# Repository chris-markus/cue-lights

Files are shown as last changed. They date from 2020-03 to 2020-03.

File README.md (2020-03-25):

# DIY Cue Light System

This Repo contains all of the neccesary hardware and software to implement a 10 station cue light system for use in a theater or other semi-permanent installation. As of March 2020, you can put this system together for well under $500.00 which is exceptional value when compared with competing commercial products. This project was originally developed for the Tufts University Theater department and is currently installed in the Balch Arena Theater.

For videos and photos of the finished system (and proof that it works...) visit the [project page](https://chrismarkus.me/cue-lights) on my website.

DISCLAIMER: *This project is intended for ADVANCED users only! That is, you need advanced soldering skills and an in-depth understanding of circuits and electrical systems is recommended to put it together. I am not responsible for any damages should you choose to put this system together yourself - use at your own risk...*

## Contents

**/controller:** Contains Arduino code that runs on the Arduino Mega that acts as the controller for the system.  
**/reciever:** Contains Arduino code that runs on the arduino nano inside of each cue light box.  
**/hardware_controller:** Contains schematics and guides for building the controller box.  
**/hardware_receiver:** Contains schematics, guides, and PCB (Printed Circuit Board) manufacturing files to order the circuit boards within each cue light box.

## Getting Started

If you would like to replicate this project, I recommend you do a few things first:

1. Read the entirety of these instructions (there are a few subtleties that could make or break the project for you)!
2. Make sure you can source all of the parts needed to build the final product or suitable replacements (See a parts list [here](https://github.com/chris-markus/cue-lights/blob/master/parts_list.md)).
3. Make sure you have the neccesary tools:
    - Soldering Iron, Solder, Flux, tweezers (there is 1 surface mount component)
    - Access to a laser cutter **or** a drill, files, and lots of patience.
    - A rotary tool or other plastic-cutting solution if you are using the same boxes for the clue light stations as I was (you will have to make some square holes in the boxes for the ethernet jacks - more on that later).

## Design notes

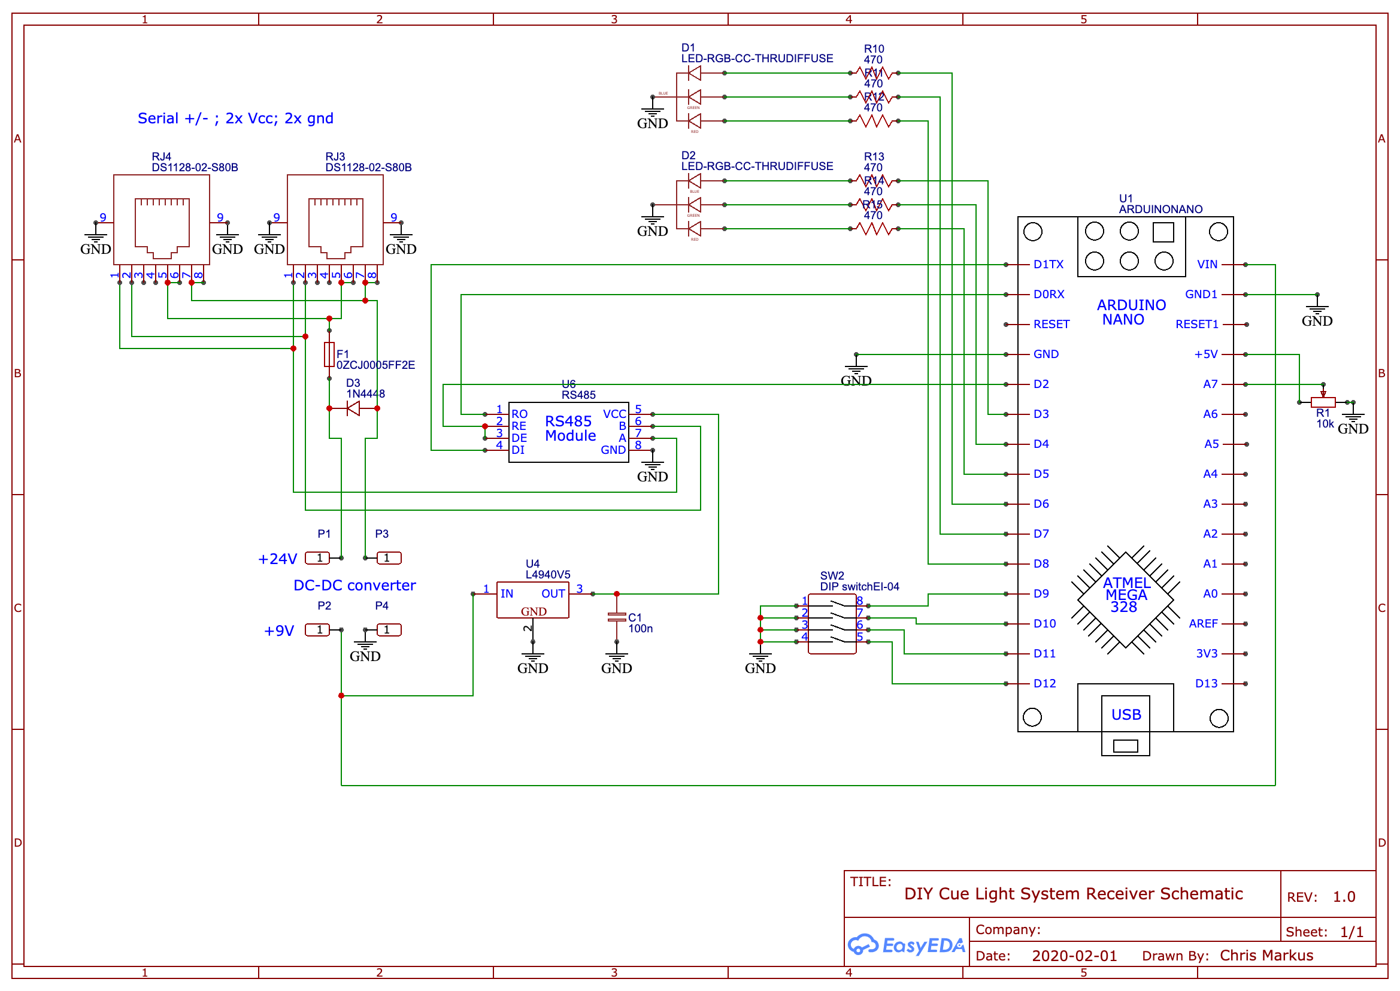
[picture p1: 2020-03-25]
hardware_reciever/reciever_schematic.png

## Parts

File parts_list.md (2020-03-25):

# Parts List

*All of these part links are what I used but the parts are certainly available elsewhere or from other sellers on Amazon. This list was compiled in March 2020 and availability may change.*

| Qty. | Description | Link | Total Price |
| - | - | - | - |
| 1 | Arduino Mega | [Amazon](https://www.amazon.com/dp/B01H4ZDYCE/?coliid=I38YO9YL3XBXYL&colid=2FJIVCIG61FZ3&psc=1&ref_=lv_ov_lig_dp_it)
| 1 | Pack of headers | [Amazon](https://www.amazon.com/dp/B074HVBTZ4/?coliid=I2SALIENF1E35N&colid=2FJIVCIG61FZ3&psc=1&ref_=lv_ov_lig_dp_it)
| 1 | Pack of hookup wires | [Amazon](https://www.amazon.com/dp/B01EV70C78/?coliid=I25YAA6RHEZLDY&colid=2FJIVCIG61FZ3&psc=1&ref_=lv_ov_lig_dp_it)
| 10 | Arduino Nano | [Amazon](https://www.amazon.com/Longruner-ATmega328P-Controller-Module-Arduino/dp/B01MSYWE6B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)
| 11+ | Max485 Module | [Amazon](https://www.amazon.com/Max485-Chip-RS-485-Module-Raspberry/dp/B00NIOLNAG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)
| 11+ | Buck Converter | [Amazon](https://www.amazon.com/dp/B01GJ0SC2C/?coliid=I3JBHTT7ABGMOY&colid=2FJIVCIG61FZ3&psc=1&ref_=lv_ov_lig_dp_it)
| 1 | 24V Power Adapter<sup>1</sup> (>30W) | [Amazon](https://www.amazon.com/gp/product/B01MUHM9RS/ref=ppx_yo_dt_b_asin_title_o06_s00?ie=UTF8&th=1)
| 1 | Female DC Barrel Jack | [Amazon](https://www.amazon.com/gp/product/B07MPS3QD8/ref=ppx_yo_dt_b_asin_title_o04_s00?ie=UTF8&psc=1)
| 10 | Project boxes (at least 9.6 x 5.6 x 2.3 cm inner dimension) | [Amazon](https://www.amazon.com/dp/B07G8S6XLV/?coliid=I3E26J4OOMT4EH&colid=2FJIVCIG61FZ3&psc=1&ref_=lv_ov_lig_dp_it)
| 10 | 4-bank of dip-switches | [Amazon](https://www.amazon.com/dp/B07V3579RT/?coliid=IUU33GC5I2TAI&colid=2FJIVCIG61FZ3&psc=1&ref_=lv_ov_lig_dp_it)
| 1 | OLED Display (Adafruit SSD1306 compatible) | [Amazon](https://www.amazon.com/dp/B076WXR8N9/?coliid=I19JJOJC0VQFZV&colid=2FJIVCIG61FZ3&psc=1&ref_=lv_ov_lig_dp_it)
| 1 | Project Enclosure (this one was really great quality) | [Amazon](https://www.amazon.com/dp/B005T58ZTO/?coliid=I29AJ8ZW90XZUX&colid=2FJIVCIG61FZ3&psc=1&ref_=lv_ov_lig_dp_it)
| 32+ | 10mm RGB LED (Common Cathode) | [Amazon](https://www.amazon.com/dp/B01CI6EWHK/?coliid=I1IVWGD1GD914&colid=2FJIVCIG61FZ3&psc=1&ref_=lv_ov_lig_dp_it)
| | Component order (From DigiKey)<sup>2</sup> | [Saved Cart](https://www.digikey.com/short/zjcjcv) | $72.72+ shipping |

<sup>1</sup> Be sure to get one that is UL-Listed  
<sup>2</sup> The quantities in the cart are (as best I can recall) EXACT. It is a fantastic idea to order extra of everything (and in some cases will actually be less expensive due to volume pricing).

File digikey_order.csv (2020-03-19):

Index | Quantity | Part Number | Manufacturer Part Number | Description | Customer Reference | Available | Backorder | Unit Price | Extended Price USD
1 | 1 | RXEF110-ND | RXEF110 | PTC RESET FUSE 72V 1.1A RADIAL |  | 1 | 0 | 0.46000 | 0.46
2 | 1 | 401-1288-ND | DA102J12S215PQF | SWITCH ROCKER SPST 16A 125V |  | 0 | 1 | 1.32000 | 1.32
3 | 1 | CF14JT120RCT-ND | CF14JT120R | RES 120 OHM 1/4W 5% AXIAL |  | 1 | 0 | 0.10000 | 0.10
4 | 1 | 1568-1601-ND | COM-10002 | KNOB KNURLED 0.236" METAL |  | 1 | 0 | 1.50000 | 1.50
5 | 32 | 1N4148FSCT-ND | 1N4148TR | DIODE GEN PURP 100V 200MA DO35 |  | 32 | 0 | 0.05360 | 1.72
6 | 10 | 507-1793-1-ND | 0ZCJ0005FF2E | PTC RESET FUSE 60V 50MA 1206 |  | 10 | 0 | 0.12500 | 1.25
7 | 1 | PEC11R-4215F-S0024-ND | PEC11R-4215F-S0024 | ROTARY ENCODER MECHANICAL 24PPR |  | 0 | 1 | 1.68000 | 1.68
8 | 11 | 493-12812-1-ND | UVR2A0R1MDD1TD | CAP ALUM 0.1UF 20% 100V RADIAL |  | 11 | 0 | 0.16400 | 1.80
9 | 11 | 497-1404-5-ND | L4940V5 | IC REG LINEAR 5V 1.5A TO220AB |  | 11 | 0 | 1.35100 | 14.86
10 | 22 | CF14JT10K0CT-ND | CF14JT10K0 | RES 10K OHM 1/4W 5% AXIAL |  | 22 | 0 | 0.04000 | 0.88
11 | 66 | CF14JT470RCT-ND | CF14JT470R | RES 470 OHM 1/4W 5% AXIAL |  | 66 | 0 | 0.02200 | 1.45
12 | 11 | BC33740TACT-ND | BC33740TA | TRANS NPN 45V 0.8A TO-92 |  | 11 | 0 | 0.24600 | 2.71
13 | 22 | AE10387-ND | A-2004-2-4-LPS-N-R | CONN MOD JACK 8P8C R/A SHIELDED |  | 22 | 0 | 0.92300 | 20.31
14 | 11 | 401-1976-ND | D6R50 F1 LFS | SWITCH PUSH SPST-NO 0.1A 32V |  | 11 | 0 | 1.17000 | 12.87
15 | 11 | 401-1975-ND | D6R40 F1 LFS | SWITCH PUSH SPST-NO 0.1A 32V |  | 11 | 0 | 0.89200 | 9.81

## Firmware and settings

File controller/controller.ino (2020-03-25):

// =====================================================
// Copyright (C) 2020 Christopher Markus 
// www.chrismarkus.me
// This software is licensed under the GNU GPLv3 License
// =====================================================

// Required libraries:
// Encoder: Arduino Package Manager
// Wire.h: Arduino Package Manager
// Adafruit_SSD1306: Arduino Package Manager
// EEPROM: included with Arduino
// Adafruit_GFX: Arduino Package Manager
// digitalWriteFast: install from here: https://github.com/NicksonYap/digitalWriteFast
// CueLightsCommon: In git repo (follow instructions in README)

// include libraries
#define ENCODER_OPTIMIZE_INTERRUPTS
#include <Encoder.h>
#include <Wire.h>
#include <EEPROM.h>
#include <digitalWriteFast.h>

// include our source files
#include <CueLightsCommon.h>
#include "strings.h"
#include "lcd_screen.h"
#include "ui_controller.h"
#include "menu.h"
#include "settings.h"
#include "constants.h"
#include "station.h"

// uncomment the following line to allow debug printing
// #define DEBUG

// some global objects
CLCDebouncedButton encoderButton(encoderButtonPin, ACTIVE_LOW_PULLUP);
LCDScreen screen(SCREEN_WIDTH, SCREEN_HEIGHT, &Wire);
Encoder encoder(encoderPins[0], encoderPins[1]);
// references to our UI controllers
NavigationController* navigation;
UIController* interface;
// panel buttons
CLCDebouncedButton stationButtons[(MAX_STATIONS + 1)][2] = {47,47,45,45,43,43,41,41,39,39,37,37,35,35,33,33,31,31,29,29,27,27};

// global status
enum GlobalStatusEnum {
  BUSY,
  OK,
  FAULT,
} GlobalStatus = BUSY;

// states for cue light communication state machine
enum ControllerState {
  STATION_REQUEST,
  STATION_RESPONSE,
  SEND_COLOR,
  BREAK,
  WAIT,
};

// Interrupt Service Routine to update panel LEDs every 0.5ms and ensure no flickering
// If you use pixel-mapped leds, this will no longer be neccessary!
ISR(TIMER4_OVF_vect) {
  TCNT4 = TIMER_COUNTER_PRELOAD;
  static int i = 0;
  analogWrite(ledPwmPins[0], 0);
  analogWrite(ledPwmPins[1], 0);
  analogWrite(ledPwmPins[2], 0);
  // use a macro to write using digitalWriteFast
  digitalWriteLEDEnable(i, LOW);
  i = (i + 1) % (MAX_STATIONS + 1);
  digitalWriteLEDEnable(i, HIGH);
  analogWrite(ledPwmPins[0], panelIndicators[i].r);
  analogWrite(ledPwmPins[1], panelIndicators[i].g);
  analogWrite(ledPwmPins[2], panelIndicators[i].b);
}

unsigned long birthTime;

void setup() {
  // pin setup that isn't taken care of by classes/other functions:
  pinMode(transmitPin, OUTPUT);
  digitalWrite(transmitPin,LOW);
  for (int i=0; i<3; i++) {
    pinMode(statusLEDPins[i], OUTPUT);
  }
  updateGlobalStatusLED();

  pinMode(buttonStbyEnable, OUTPUT);
  pinMode(buttonGoEnable, OUTPUT);

  #ifdef DEBUG
  Serial.begin(CLC_DEFAULT_BAUD_RATE);
  #endif

  // initialize settings and stations (cue light boxes):
  InitSettings();
  InitStations();

  // begin serial connection(s)
  STATION_SERIAL.begin(CLC_DEFAULT_BAUD_RATE);

  // setup ISR and change pwm frequency
  noInterrupts();
  // setup ISR on timer 4 to run face panel light code
  TCCR4A = 0;
  TCCR4B = 0;
  TIMSK4 |= (1 << TOIE1); // enable timer overflow interrupt
  TCCR4B |= (1 << CS12); // 256 prescaler
  TCNT4 = TIMER_COUNTER_PRELOAD; // preload timer 65536-16MHz/256/2Hz

  // increase PWM frequency of timers 1 and 2 to help reduce panel light flickering
  TCCR2B = TCCR2B & 0b11111000 | 0x01;
  TCCR1B = TCCR1B & 0b11111000 | 0x01;
  interrupts();

  // screen setup
  screen.init();
  screen.showSplash();

  // Screens created in menu-definitions.ino
  navigation = new NavigationController(&screen, &homeScreen);
  interface = new UIController(&encoder, &encoderButton, navigation);

  birthTime = millis();
}

bool initialSet = false;

void loop() {
  if (!initialSet && millis() > birthTime + 1000) {
    GlobalStatus = OK;
    initialSet = true;
  }
  detectButtonPresses();
  updateFacePanelLights();
  interface->tick();
  updateGlobalStatusLED();
  HandleCommunication();
}

void resetSettings() {
  resetDefaultSettings();
  navigation->goHome();
}

void getConnStatusString(char* input) {
  uint8_t count = 0;
  for(int i=0; i<MAX_STATIONS; i++) {
    count += stations[i].connStatus == CONNECTED;
  }
  sprintf(input, STR_LIGHTS_STATUS, count);
}

int getNextDisconnectedStation(int& numDisconnected) {
  static unsigned long lastUpdate = 0;
  const uint16_t updateInterval = 1500;
  static int currentStation = 0;
  bool connected[MAX_STATIONS];
  bool fault = false;
  numDisconnected = 0;
  for (int i=0; i<MAX_STATIONS; i++) {
    if (stations[currentStation].connStatus != CONNECTED 
        && stations[i].lastSeen != 0
        && millis() - stations[i].lastSeen > STATION_DISCONNECT_TIMEOUT 
        && millis() - stations[i].lastSeen < 100000)
    {
      if (millis() - stations[i].lastSeen < 10000) {
        fault = true;
      }
      connected[i] = false;
      numDisconnected++;
    }
    else {
      connected[i] = true;
    }
  }
  if (stations[currentStation].connStatus == CONNECTED || millis() > lastUpdate + updateInterval) {
    lastUpdate = millis();
    for (int i=currentStation+1; i<MAX_STATIONS + currentStation + 1; i++) {
      if (!connected[i%MAX_STATIONS]) {
        currentStation = i%MAX_STATIONS;
        break;
      }
    }
  }
  if (fault) {
    GlobalStatus = FAULT;
  }
  else {
    GlobalStatus = OK;
  }
  if (numDisconnected > 0) {
    return currentStation;
  }
  else {
    return -1;
  }
}

void getGlobalStatusString(char* input) {
  int numIssues = 0;
  int i = getNextDisconnectedStation(numIssues);
  if (i != -1) {
    sprintf(input, STR_ISSUES, numIssues);
  }
  else {
    sprintf(input, STR_NO_ISSUES);
  }
}

void getDescriptiveGlobalStatusString(char* input) {
  int numIssues = 0;
  int i = getNextDisconnectedStation(numIssues);
  if (i != -1) {
    sprintf(input, STR_STATION_DISCONNECTED, i+1, (millis() - stations[i].lastSeen)/1000);
  }
  else {
    sprintf(input, STR_NO_ISSUES);
  }
}

void detectButtonPresses() {
  // row 0 is standby, 1 is go
  static int buttonRow = false;
  static bool canSwap[MAX_STATIONS] = {1,1,1,1,1,1,1,1,1,1};

  digitalWrite(buttonStbyEnable, buttonRow);
  digitalWrite(buttonGoEnable, !buttonRow);

  // button press detection loop
  for (int i=0; i<MAX_STATIONS; i++) {
    if (stations[i].connStatus == CONNECTED) {
      CueStatus status = stations[i].cueStatus;
      if (stationButtons[i][buttonRow].isPressed()) {
        if (canSwap[i]) {
          if (status == NONE || buttonRow != (status == STBY)) {
            // if the status is none or if the status is not the same as the 
            // button we are pressing, set the status to correspond to the button
            stations[i].cueStatus = buttonRow?STBY:GO;
          }
          else {
            // otherwise, set it to NONE
            stations[i].cueStatus = NONE;
          }
          canSwap[i] = false;
        }
      }
      else if (stationButtons[i][buttonRow].wasReleased()) {
        canSwap[i] = true;
      }
    }
  }

  // master stby or go pressed
  if (stationButtons[MAX_STATIONS][buttonRow].isPressed()) {
    for (int i=0; i<MAX_STATIONS; i++) {
      switch (stations[i].cueStatus) {
        case STBY:
            stations[i].cueStatus = buttonRow?NONE:GO;
          break;
        case GO:
          if (buttonRow) {
            stations[i].cueStatus = NONE;
          }
          break;
        case NONE:
          break;
      }
    }
  }

  buttonRow = !buttonRow;
}

void updateFacePanelLights() {
  static bool flashOn = true;
  static unsigned long lastFlashChange = 0;

  if (flashOn && millis() > FLASH_DELAY_ON + lastFlashChange || 
      !flashOn && millis() > FLASH_DELAY_OFF + lastFlashChange)
  {
    flashOn = !flashOn;
    lastFlashChange = millis();
  }

  int stby = -1;
  int go = -1;
  int connected = -1;

  // color update loop
  for(int i=0; i< MAX_STATIONS; i++) {
    if (stations[i].connStatus == CONNECTED) {
      connected = i;
      if (stations[i].cueStatus == STBY) {
        stby = i;
        if (!flashOnStandby.value || flashOnStandby.value && flashOn) {
          stations[i].color = getScaledColor(RGBColor {standbyColor[0].value, standbyColor[1].value, standbyColor[2].value},
                                             stationBrightness[i].max,
                                             stationBrightness[i].value);
        }
        else {
          stations[i].color = {0,0,0};
        }
        panelIndicators[i] = getScaledColor(stations[i].color, panelBrightness.max, panelBrightness.value);
      }
      else if (stations[i].cueStatus == GO) {
        go = i;
        stations[i].color = getScaledColor(RGBColor {goColor[0].value, goColor[1].value, goColor[2].value},
                                           stationBrightness[i].max,
                                           stationBrightness[i].value);
        panelIndicators[i] = getScaledColor(stations[i].color, panelBrightness.max, panelBrightness.value);
      }
      else {
        stations[i].color = {0,0,0};
        panelIndicators[i] = {0,0,12};
      }
    }
    else {
      panelIndicators[i] = {0,0,0};
    }
  }

  if (stby != -1) {
    if (!flashOnStandby.value || flashOnStandby.value && flashOn) {
      panelIndicators[MAX_STATIONS] = getScaledColor(RGBColor {standbyColor[0].value, standbyColor[1].value, standbyColor[2].value},
                                                     panelBrightness.max,
                                                     panelBrightness.value);
    }
    else {
      panelIndicators[MAX_STATIONS] = {0,0,0};
    }
  }
  else if (go != -1) {
    panelIndicators[MAX_STATIONS] = getScaledColor(RGBColor {goColor[0].value, goColor[1].value, goColor[2].value},
                                                   panelBrightness.max,
                                                   panelBrightness.value);
  }
  else if (connected != -1) {
    panelIndicators[MAX_STATIONS] = panelIndicators[connected];
  }
  else {
    panelIndicators[MAX_STATIONS] = {0,0,0};
  }
}

RGBColor getScaledColor(RGBColor c, uint8_t max, uint8_t value) {
  c.r = (uint8_t)((uint16_t)(c.r)*(uint16_t)(value)/(uint16_t)(max));
  c.g = (uint8_t)((uint16_t)(c.g)*(uint16_t)(value)/(uint16_t)(max));
  c.b = (uint8_t)((uint16_t)(c.b)*(uint16_t)(value)/(uint16_t)(max));
  return c;
}

// Handles all communication with the cue light stations. See "CueLightsCommon.h" for 
// in-depth protocol descriptions.
void HandleCommunication() {
  static ControllerState controllerState = BREAK;
  static uint8_t responseStation = 0;
  int len = 0;
  char sendBuff[CLC_DATA_LEN + CLC_OVERHEAD]; // start + type + data + 2 end chars
  static char recvBuffer[CLC_STATUS_LEN + CLC_OVERHEAD + 1]; // start + type + synced + end
  static int recvIndex = 0;
  static unsigned long requestSent = 0;
  static unsigned long waitStart = 0;
  bool doneReceiving = false;
  char ch;

  switch(controllerState) {
    case SEND_COLOR:
      sendBuff[len++] = CLC_PKT_START;
      sendBuff[len++] = PKT_TYPE_CONTROL;
      for (int i=0; i<MAX_STATIONS; i++) {
        sendBuff[len++] = stations[i].color.r;
        sendBuff[len++] = stations[i].color.g;
        sendBuff[len++] = stations[i].color.b;
      }
      sendBuff[len++] = CLC_PKT_END;

      STATION_SERIAL.write(sendBuff, len);
      controllerState = STATION_REQUEST;
      break;
    case STATION_REQUEST:
      sendBuff[len++] = CLC_PKT_START;
      sendBuff[len++] = PKT_TYPE_STATUS;
      sendBuff[len++] = (char)(stations[responseStation].address);
      sendBuff[len++] = CLC_PKT_END;

      STATION_SERIAL.write(sendBuff, len);
      requestSent = millis();

      // need to make sure everything has been sent before we switch
      // no need to do this asynchronously since the delay is so short
      STATION_SERIAL.flush();
      delay(1);
      // ready to recieve
      digitalWriteFast(transmitPin, LOW);
      delay(1);

      controllerState = STATION_RESPONSE;
      break;
    case STATION_RESPONSE:
      if(STATION_SERIAL.available()) {
        ch = STATION_SERIAL.read();
        if (ch == CLC_PKT_START) {
          recvIndex = 0;
          recvBuffer[recvIndex++] = ch;
        }
        else if (recvIndex < CLC_STATUS_LEN + CLC_OVERHEAD) {
          recvBuffer[recvIndex++] = ch;
        }
      }

      // recieved packet: |START|TYPE|ADDRESS (as char)|SYNCHRONIZED (as char)|END|
      //         example: | '<' |'R' |      0x03       |         0x01         |'>'|
      // we care about the synchronized byte because the cue light will not accept color commands if it is not synchronized
      if (recvIndex == CLC_STATUS_LEN + CLC_OVERHEAD &&
          recvBuffer[0] == CLC_PKT_START &&
          recvBuffer[1] == PKT_TYPE_RESPONSE &&
          recvBuffer[2] == stations[responseStation].address &&
          recvBuffer[3] == 1) {
        stations[responseStation].connStatus = CONNECTED;
        stations[responseStation].lastSeen = millis();
        doneReceiving = true;
      }
      else if (millis() > requestSent + CLC_RESPONSE_TIMEOUT) {
        #ifdef DEBUG
          Serial.print("Timeout ");
          Serial.println(stations[responseStation].address);
        #endif
        if (stations[responseStation].lastSeen < millis() - STATION_DISCONNECT_TIMEOUT) {
          stations[responseStation].connStatus = DISCONNECTED;
        }
        doneReceiving = true;

        // clear the recieve buffer
        while(STATION_SERIAL.available()) {
          STATION_SERIAL.read();
        }
      }

      if (doneReceiving) {
        digitalWriteFast(transmitPin, HIGH);
        responseStation = (responseStation + 1) % MAX_STATIONS;
        recvIndex = 0;
        delay(1);
        controllerState = BREAK;
      }
      break;
    case BREAK:
      for (int i=0; i<CLC_BREAK_LEN; i++) {
        sendBuff[len++] = CLC_PKT_END;
      }
      STATION_SERIAL.write(sendBuff, len);
      waitStart = millis();
      controllerState = WAIT;
      break;
    case WAIT:
      if (millis() > waitStart + CLC_RESPONSE_DELAY) {
        controllerState = SEND_COLOR;
      }
      break;
  }
}

void updateGlobalStatusLED() {
  const int brightness = 3;
  switch(GlobalStatus) {
    case BUSY:
      digitalWrite(statusLEDPins[1], 0);
      digitalWrite(statusLEDPins[0], 0);
      flashLED(statusLEDPins[2], 50, brightness);
      break;
    case OK:
      analogWrite(statusLEDPins[0], brightness*1.5);
      analogWrite(statusLEDPins[1], brightness/2.0);
      analogWrite(statusLEDPins[2], brightness/1.5);
      break;
    case FAULT:
      flashLED(statusLEDPins[0], 100, 30);
      digitalWrite(statusLEDPins[1], 0);
      digitalWrite(statusLEDPins[2], 0);
      break;
  }
}

void flashLED(int pin, unsigned int delay, uint8_t brightness) {
    static unsigned long lastStateSwitch = 0;
    static bool lastState = false;
    unsigned long timeNow = millis();
    if (timeNow - delay > lastStateSwitch) {
        lastState = !lastState;
        analogWrite(pin, lastState?brightness:0);
        lastStateSwitch = timeNow;
    }
}

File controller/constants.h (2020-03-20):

// =====================================================
// Copyright (C) 2020 Christopher Markus 
// www.chrismarkus.me
// This software is licensed under the GNU GPLv3 License
// =====================================================

#ifndef CONSTANTS_H
#define CONSTANTS_H

#include "macros.h"

#define SCREEN_WIDTH 128 // OLED display width, in pixels
#define SCREEN_HEIGHT 64 // OLED display height, in pixels

#define ENCODER_STEPS_PER_CLICK 4 // number of steps in the encoder reading per physical click

// serial interface for remote stations
#define STATION_SERIAL Serial2

#define FLASH_DELAY_ON 1000
#define FLASH_DELAY_OFF 300

// run panel light interrupt at 2000Hz: x = 65536-16MHz/256/2000Hz
#define TIMER_COUNTER_PRELOAD 65504

// pin definitions:
const int transmitPin = 2;
const int ledEnablePins[] = {LED_EN_0,LED_EN_1,LED_EN_2,LED_EN_3,LED_EN_4,LED_EN_5,LED_EN_6,LED_EN_7,LED_EN_8,LED_EN_9,LED_EN_10};
const int ledPwmPins[] = {11, 10, 9}; // r, g, b
const int statusLEDPins[] = {5,4,3};
const int encoderPins[] = {18,19};
const int encoderButtonPin = 53;
const int buttonStbyEnable = 23;
const int buttonGoEnable = 25; // stby row, go row
const int buttonPins[] = {47,45,43,41,39,37,35,33,31,29,27};

#endif

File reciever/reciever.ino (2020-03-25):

// =====================================================
// Copyright (C) 2020 Christopher Markus 
// www.chrismarkus.me
// This software is licensed under the GNU GPLv3 License
// =====================================================

#include <CueLightsCommon.h>
#include <digitalWriteFast.h>

#define NUM_SWITCHES 4

const int ledPins[3][2] = {6,9,5,10,3,11};
const int transmitPin = 2;

const int ledBuiltinPin = 13;

//const int switchPins[4] = {4, 7, 8, 12};
// switch at spot 0 is LSB ... at 4 is MSB
CLCDebouncedButton switches[NUM_SWITCHES] = {CLCDebouncedButton(12, ACTIVE_LOW_PULLUP), 
                                             CLCDebouncedButton(8, ACTIVE_LOW_PULLUP),
                                             CLCDebouncedButton(7, ACTIVE_LOW_PULLUP),
                                             CLCDebouncedButton(4, ACTIVE_LOW_PULLUP)};

uint8_t dataBuffer[CLC_DATA_LEN];

void setup() {
  pinMode(transmitPin, OUTPUT);
  digitalWrite(transmitPin, LOW);
  pinMode(ledBuiltinPin, OUTPUT);
  Serial.begin(CLC_DEFAULT_BAUD_RATE);
  for (int i=0; i<3; i++) {
    pinMode(ledPins[i][0], OUTPUT);
    pinMode(ledPins[i][1], OUTPUT);
  }
}

bool synchronized = false;
uint8_t syncCounter = 0;
unsigned long lastSuccessfulPacket = 0;
unsigned long lastForceDesync = 0;

void loop() {
  uint8_t ndx = 0;
  char rc = 0;
  bool shouldRespond = false;
  MessageProgressState state = STATE_START;
  bool willDesync = false;
  // the end packet symbol could show up in our color data so we protect
  // against it here and make sure we synchronize by sending a "break" sequence
  // of end symbols for at least the length of the data every few packets.
  while (rc != CLC_PKT_END || state == STATE_DATA) {
    // force a desynchronization if it has been a while since the last successful packet
    // AND it has been a while since we forced a desynchronization (to allow time to 
    // recieve a successful packet)
    if (synchronized &&
        millis() > lastSuccessfulPacket + STATION_DISCONNECT_TIMEOUT &&
        millis() > lastForceDesync + STATION_DISCONNECT_TIMEOUT)
    {
      syncCounter = 0;
      synchronized = false;
      lastForceDesync = millis();
    }
    if (Serial.available()) {
      rc = Serial.read();

      if (!synchronized && rc == CLC_PKT_END) {
        syncCounter++;
      }
      else if (!synchronized && rc != CLC_PKT_END) {
        if (syncCounter >= CLC_BREAK_LEN - 2) {
          synchronized = true;
        }
        syncCounter = 0;
      }

      switch(state) {
        case STATE_START:
          if (rc == CLC_PKT_START) {
            state = STATE_TYPE;
          }
          break;
        case STATE_TYPE:
          if (rc == PKT_TYPE_CONTROL) {
            state = STATE_DATA;
          }
          else if (rc == PKT_TYPE_STATUS) {
            state = STATE_STATUS;
          }
          else {
            state = STATE_END;
          }
          break;
        case STATE_DATA:
          if (ndx < CLC_DATA_LEN) {
            dataBuffer[ndx++] = rc;
          }
          else {
            if (synchronized) {
              lastSuccessfulPacket = millis();
              updateLEDs();
            }
            state = STATE_END;
          }
          break;
        case STATE_STATUS:
          if (rc == getAddress()) {
            shouldRespond = true;
          }
          // desync when we reach station 10 so we force a re-sync
          if (rc == MAX_STATIONS - 1) {
            willDesync = true;
          }
          state = STATE_END;
          break;
        case STATE_END:
          // do nothing - the while loop will end us
          break;
      }
    }
    digitalWrite(ledBuiltinPin, synchronized);
  }

  if (shouldRespond) {
    digitalWriteFast(transmitPin, HIGH);
    delay(CLC_STATE_SWITCH_DELAY + 1);
    char buf[5];
    int len = 0;
    buf[len++] = CLC_PKT_START;
    buf[len++] = PKT_TYPE_RESPONSE;
    buf[len++] = getAddress();
    buf[len++] = (uint8_t)(synchronized);
    buf[len++] = CLC_PKT_END;
    Serial.write(buf, len);
    delay(1);
    digitalWriteFast(transmitPin, LOW);
    delay(CLC_STATE_SWITCH_DELAY);
  }

  if (willDesync) {
    synchronized = false;
    syncCounter = 0;
  }
}

uint8_t getAddress() {
  uint8_t address = 0;
  for(uint8_t i=0; i<NUM_SWITCHES; i++) {
    address += (uint8_t)(switches[i].isPressed())<<i;
  }
  return address;
}

void updateLEDs() {
  if (getAddress()-1 < 0 || 3*(getAddress()-1) + 2 >= MAX_STATIONS*3) {
    return;
  }
  for(int i=0, j=3*(getAddress()-1); i<3; i++, j++) {
    analogWrite(ledPins[i][0], dataBuffer[j]);
    analogWrite(ledPins[i][1], dataBuffer[j]);
  }
}

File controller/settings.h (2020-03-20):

// =====================================================
// Copyright (C) 2020 Christopher Markus 
// www.chrismarkus.me
// This software is licensed under the GNU GPLv3 License
// =====================================================

#ifndef SETTINGS_H
#define SETTINGS_H

#include <Arduino.h>

#include <CueLightsCommon.h>

#define NUM_SETTINGS 18

// version of settings (change this whenever changes are made to SettingsEEPROMData struct)
#define SETTINGS_ITERATION 1

#define EEPROM_CRC_ADDRESS EEPROM.length() - sizeof(unsigned long)
// offset the start of our data by the size of the crc (which is stored at 0)
#define EEPROM_SETTINGS_ADDRESS 0


#define SETTING_PANEL_BRIGHTNESS "Panel Brightness"
//#define SETTING_PANEL_BRIGHTNESS_ID 0
#define SETTING_FLASH_STANDBY "Flash on Standby"
//#define SETTING_FLASH_STANDBY_ID 1
#define SETTING_STATION_BRIGHTNESS "Station %d Brightness"
//#define SETTING_STATION_BRIGHTNESS_ID 2 // there are 10 of them

//#define SETTING_STBY_COLOR_ID 12 // 3 of them
//#define SETTING_GO_COLOR_ID 15 // 3 of them

enum SettingType {
    BOOL,
    VALUE
};

struct Setting {
    const char* name;
    uint8_t value;
    uint8_t max;
    uint8_t min;
    SettingType type;
};

extern Setting panelBrightness;
extern Setting stationBrightness[MAX_STATIONS];
extern Setting standbyColor[3];
extern Setting goColor[3];
extern Setting flashOnStandby;


// struct for storing settings values to eeprom; ALL SIZES ARE HARDCODED to avoid any unfortunate mix-ups...
#if MAX_STATIONS != 10
    #error "You changed the number of stations, please update the eeprom struct to match (in settings.h)"
#endif


struct SettingsEEPROMData {                     // Offsets from start address: (eeprom is byte-addressable)
    int iteration = SETTINGS_ITERATION;         // 0
    uint8_t panelBrightness;                    // 2
    uint8_t stationBrightness[10];              // 3
    uint8_t standbyColor[3];                    // 13
    uint8_t goColor[3];                         // 16
    uint8_t flashOnStandby;                     // 19
};

// forward declarations:
void saveSettings();

#endif

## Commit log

2020-03-19 some intense code cleanup and beginning readme's
    [Gerber_BoardOutline.GKO, Gerber_BottomLayer.GBL, Gerber_BottomSilkLayer.GBO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]
2020-03-25 added reciever schematic, changed some constants after testing
    [Gerber_BoardOutline.GKO, Gerber_BottomLayer.GBL, Gerber_BottomSilkLayer.GBO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]
2020-03-25 updated schematic
